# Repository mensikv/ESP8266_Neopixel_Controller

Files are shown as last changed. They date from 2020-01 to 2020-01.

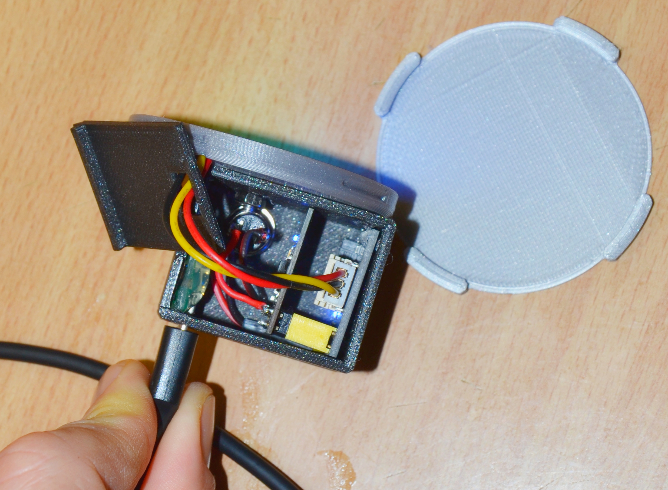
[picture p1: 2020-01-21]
img/WS2812B_controller_5.JPG

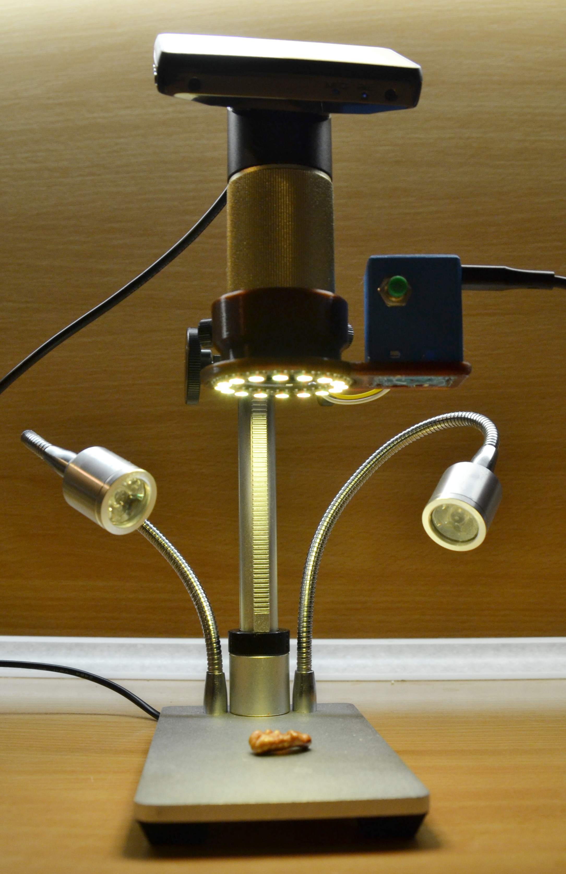
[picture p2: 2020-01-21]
img/ADSM201_WS2812B_ring_2.JPG

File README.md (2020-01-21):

# ESP8266 Neopixel Controller
I have bought a couple of ESP-01S boards without any project really in my mind. But recently I have discovered cool looking WS2812B (Neopixel) adapters for these boards, so that gave me an idea for a project.

After several iterations I have developed little device, that enables to control WS2812B strips/rings either throught web interface, through MQTT commands or through REST API. It has also one button, that can switch various colors and effects. 
What can it do:
* provides web interface that enables to select any color, save it to EEPROM, start an effect
* when enabled, the WS1228B strips can be controlled via MQTT commands (color, effect, off)
* REST API is also available to set color or effect
* button click cycles through saved colors, double click cycles through available effects and long click turns Neopixels off

Project can be used in home automation systems as it provides several interfaces that could be easily integrated into for example Node-Red.

**WIFI network is required**.

## Prerequisites
### Hardware
It is possible to use any ESP8266 board, but I used specifically ESP-01S boards (non-affiliated links):
* [WS2812B adapter for ESP-01S](https://www.aliexpress.com/item/32894024068.html?spm=a2g0s.9042311.0.0.27424c4d4m1lEc)
* [ESP-01S](https://www.aliexpress.com/item/32809618395.html?spm=a2g0s.9042311.0.0.27424c4deEkjUk) - you need the "S" version as it has more falsh memory (1MB) 
* [Momentary push button](https://www.aliexpress.com/item/32812446715.html?spm=a2g0s.9042311.0.0.27424c4d1w7nAk)
* [Micro USB connector](https://www.aliexpress.com/item/32394000673.html?spm=a2g0s.9042311.0.0.27424c4dAlAlbz)
* [16x WS1228B (Neopixel) ring](https://www.aliexpress.com/item/33006920763.html?spm=a2g0s.9042311.0.0.27424c4dT2O7Fa) - you should be able to use even more Neopixels

The push button is connected between GND and GPIO3 on the ESP-01S. When using the WS2812B adapter for ESP-01S, the control pin is GPIO2.

### Software
Project was tested with the following versions:
* Arduino IDE 1.8.10
* ESP8266 core 2.6.0
* [ESP8266 Sketch Data Upload](https://github.com/esp8266/arduino-esp8266fs-plugin)

Libraries:
* [ArduinoJSON 6.12.0](https://github.com/bblanchon/ArduinoJson)
* [ESP_EEPROM 2.0.0](https://github.com/jwrw/ESP_EEPROM)
* [FastLed 3.3](https://github.com/FastLED/FastLED)
* [WifiManages 0.15.0-beta](https://github.com/tzapu/WiFiManager)
* [PubSubClient 2.7](https://github.com/knolleary/pubsubclient)
* [PinButton](https://github.com/poelstra/arduino-multi-button)

## Setup
1. Download content of this repository to your Arduino folder (probably `~\Documents\Arduino\ESP8266_Neopixel_Controller`, folder should contain `*.ino` file and `data` folder) and then open `ESP8266_Neopixel_Controller.ino`.
1. Set pin for WS2812B input `#define LED_DATA_PIN 2` - if you are using the adapter board, do not change
1. Set number of WS2812B LEDs `#define NUM_LEDS 16`
1. Set pin for the button `#define BUTTON_PIN 3`
1. You can set a hostname by changing `#define ESP_HOSTNAME "NPCTRL001"`
1. If you want to enable MQTT API (choosing colors with MQTT messages), uncomment `//#define USE_MQTT`
   1. In section `#ifdef USE_MQTT` set connection to your MQTT broker and topics, you want to use.
   1. You should increase `MQTT_MAX_PACKET_SIZE` in PubSubClient.h. For 10 colors is 512 sufficient - `#define MQTT_MAX_PACKET_SIZE 512`
1. If you want to assign static IP address to the board in your WIFI network, uncomment and set following line `//wifiManager.setSTAStaticIPConfig(IPAddress(192,168,0,99), IPAddress(192,168,0,1), IPAddress(255,255,255,0));`
1. Choose the right board and select Flash size with at least 128kB SPIFFS, for ESP-01S it should be "Generic ESP8266 Module" and "1M (128k SPIFFS)"
1. Upload the code.
1. Run ESP8266 Sketch Data Upload to upload content of `/data` folder to SPIFFS on ESP8266. Great article is [Chapter 11 - SPIFFS](https://tttapa.github.io/ESP8266/Chap11%20-%20SPIFFS.html). ESP8266 Sketch Data Upload plug-in to load data on SPIFFS can be downloaded from [here](https://github.com/esp8266/arduino-esp8266fs-plugin). `/data` folder contains html code, CSS styles and JavaScript code for the webserver.
   1. Before stating upload to SPIFFS make sure, that Serial monitor window is not opened, otherwise the upload will fail.
1. Now the ESP8266 will start in AP mode and creates WIFI network with the name you set as hostname. Connect to this network and you should be redirected to URL 192.168.0.1 (if not, enter this address in your browser). On this page set up WIFI connection to your network. ESP8266 will try to connect to it.
1. Either check your router or Serial monitor to find out, what IP address the ESP8266 got. Enter this address in your browser.
1. You enter a web interface with 2 tabs, the 1st tab is used to set color of Neopixels or start an effect (it is empty, until you  save some colots). The 2nd tab is used to choose and save new colors.

## REST API
The provided web interface itself uses this REST API and you can easily integrate it in other projects.
* GET commands
  * http://IPADDRESS/api?color=RRGGBB&brightness=xx
    * set color of the Neopixels, returns JSON with information about success or error, brightness from 0 to 100
  * http://IPADDRESS/api?all=1
    * returns JSON with saved colors
  * http://IPADDRESS/api?off=1
    * turn Neopixels off, returns JSON with information about success or error
  * http://IPADDRESS/api?effect=effect_name
    * display desired effect, returns JSON with information about success or error, effect names: "rainbow", "rainbowGl", "confetti", "sinelon", "bpm", "juggle", "fire2012", "cylon", "sparkle", "snowspark", "meteor", "theatre"
* POST commands
  * http://IPADDRESS/api?save=1&color=RRGGBB&brightness=xx
    * save new color to EEPROM, returns JSON with information about success or error
  * http://IPADDRESS/api?delete=1&color=RRGGBB&brightness=xx
    * delete color from EEPROM, returns JSON with information about success or error

## MQTT API
If you enable MQTT API, then the ESP8266 will wait for commands in topic:
* MQTT_TOPIC/cmd/color
  * payload: RRGGBB/xx
    * set color and brightness of Neopixels, brightness from 0 to 100
* MQTT_TOPIC/cmd/effect
  * payload: effect_name
    * starts chosen effect: "rainbow", "rainbowGl", "confetti", "sinelon", "bpm", "juggle", "fire2012", "cylon", "sparkle", "snowspark", "meteor", "theatre"
* MQTT_TOPIC/cmd/all
  * returns JSON with saved colors in topic MQTT_TOPIC/rspn
* MQTT_TOPIC/cmd/off
  * turns Neopixels off

All commands return response JSON in topic MQTT_TOPIC/rspn.

## Button interface
You can use button clicks to set color, start an effect or turn Neopixels off. The button should be connected between GND and GPIO3 on the ESP01-S board (defined as BUTTON_PIN).
* Single click - sets next saved color
* Double click - starts next effect
* Long click - turns Neopixels off

## STL for case
In the folder `stl` you will find `*.stl` files for your 3D printer, so you can print nice case for this project.
More information about the case and photos can be found on [Thingiverse](https://www.thingiverse.com/thing:4118976).

If you happen to have [Andonstar ADSM201 microscope](https://www.aliexpress.com/item/32614052280.html?spm=2114.12010612.8148356.5.1d8e66adaiGyX6), you will find there a mount for this project to bring more light to yout microscope sessions.

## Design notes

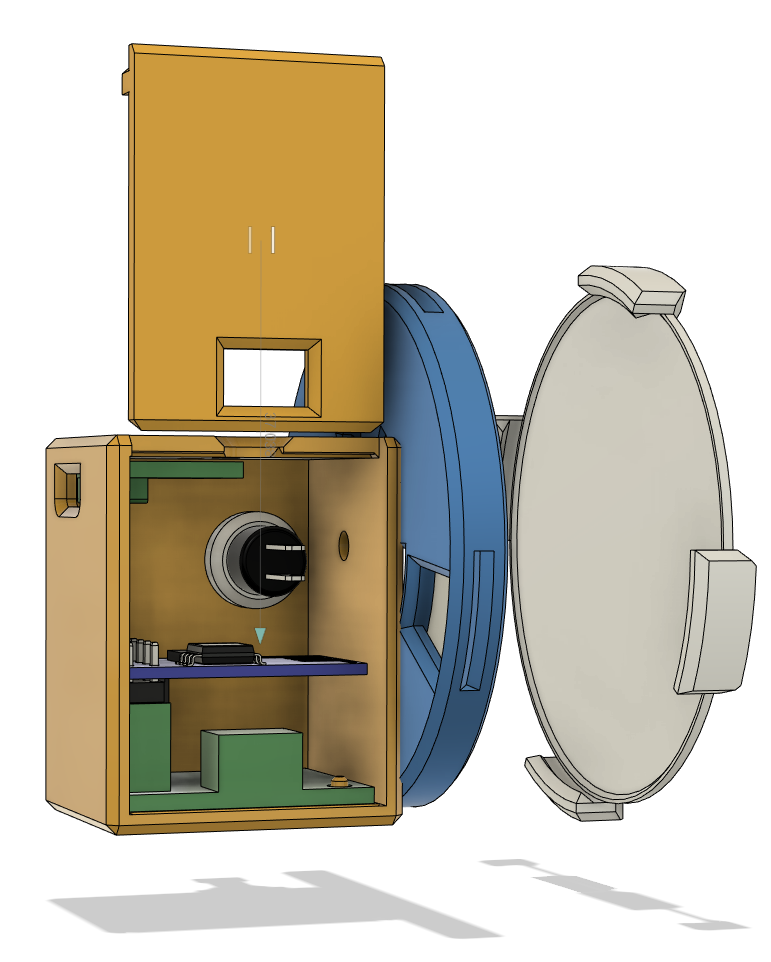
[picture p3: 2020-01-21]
img/WS2812B_controller_7.png

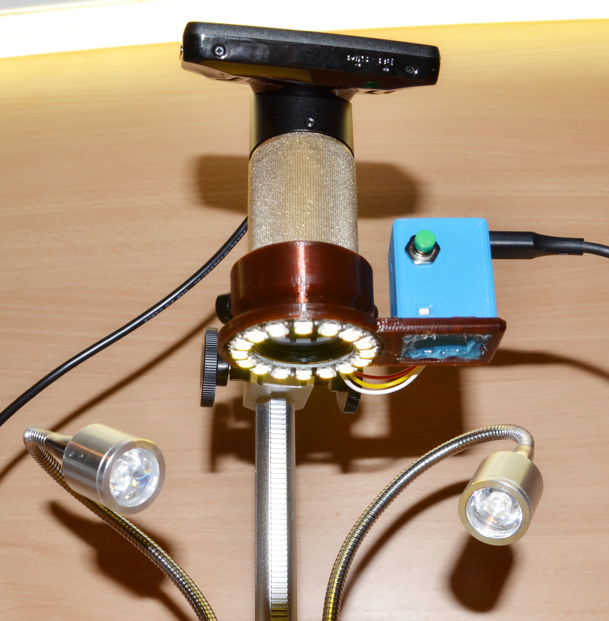
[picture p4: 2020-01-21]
img/ADSM201_WS2812B_ring_3.JPG

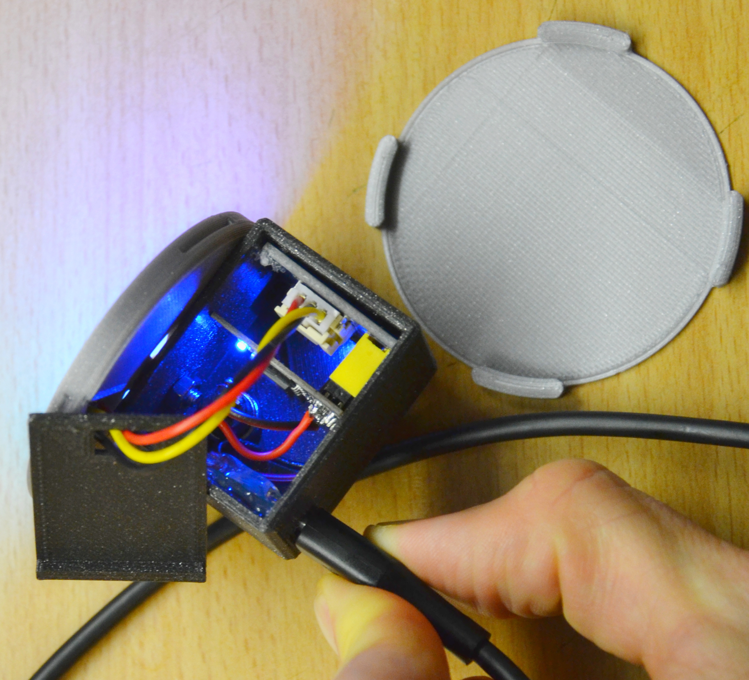
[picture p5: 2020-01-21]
img/WS2812B_controller_6.JPG

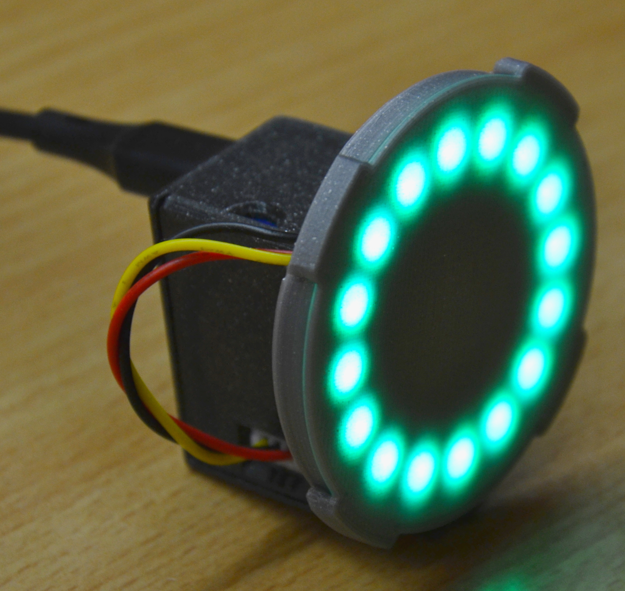
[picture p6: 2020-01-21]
img/WS2812B_controller_2.JPG

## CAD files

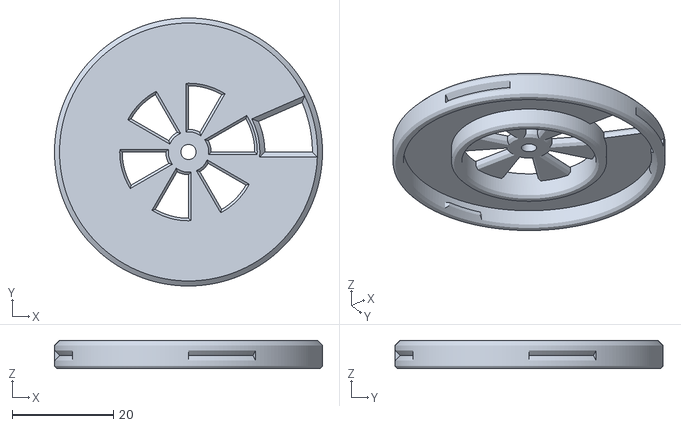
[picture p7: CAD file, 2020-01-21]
stl/WS2812B_ring_16.stl
53.0 x 53.0 x 5.60

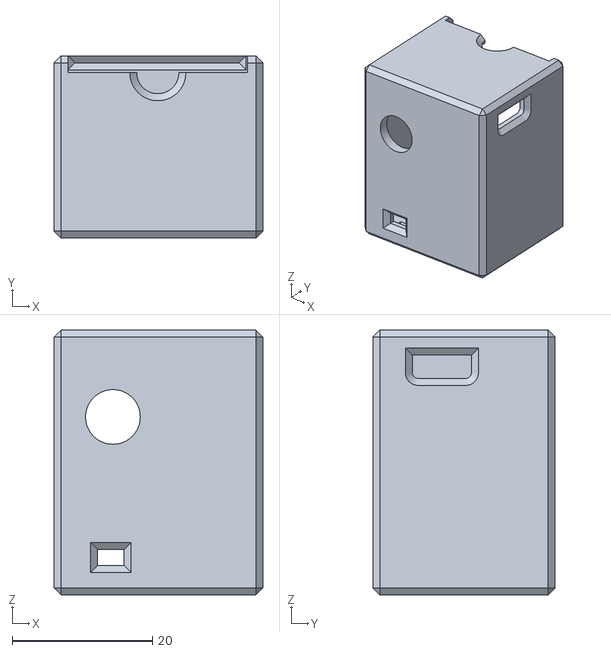
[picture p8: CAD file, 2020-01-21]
stl/WS2812B_controller_box.stl
29.8 x 26.0 x 37.8

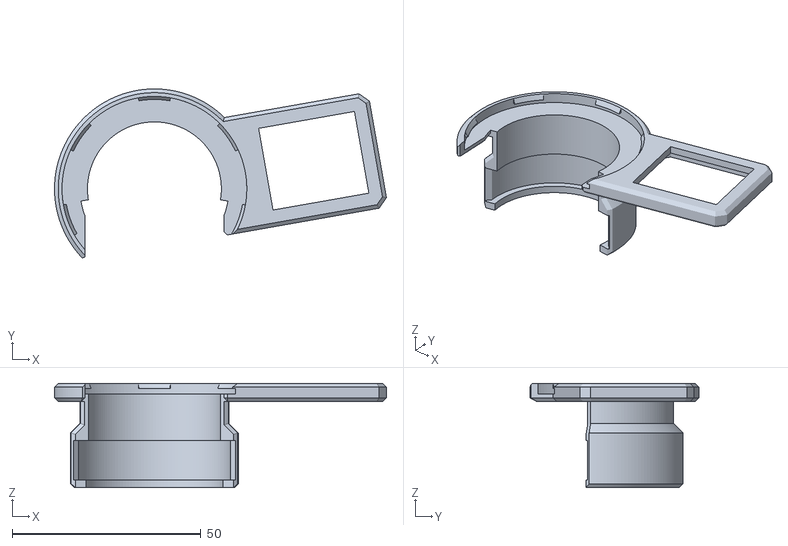
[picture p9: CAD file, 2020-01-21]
stl/ADSM201_WS2812B_ring_holder.stl
88.0 x 44.9 x 27.6

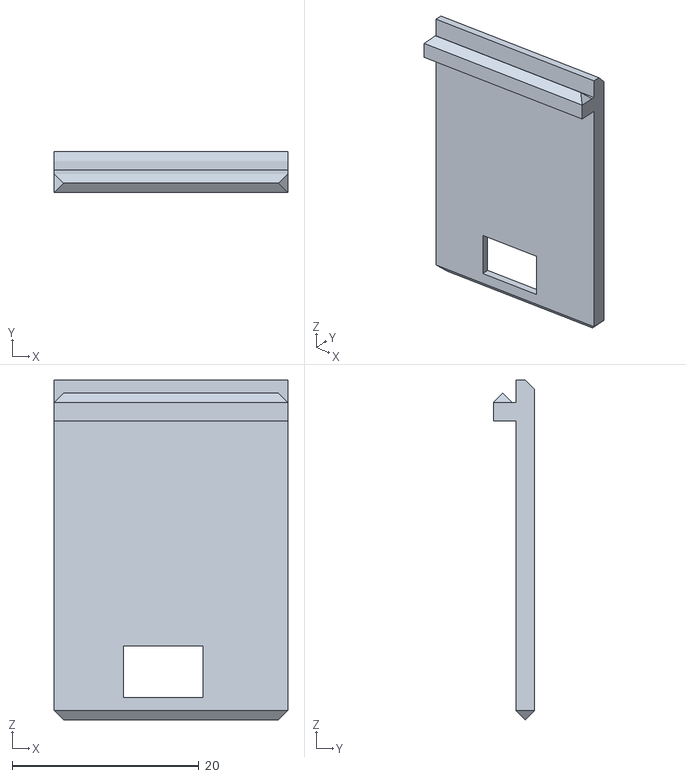
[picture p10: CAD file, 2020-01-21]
stl/WS2812B_controller_box_cover.stl
25.0 x 4.40 x 36.4

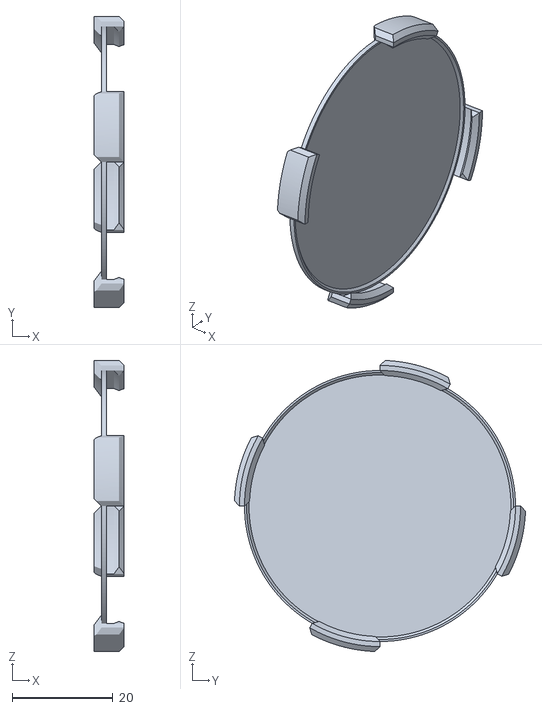
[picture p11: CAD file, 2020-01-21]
stl/WS2812B_ring_16_diffuser.stl
6.00 x 57.8 x 57.8

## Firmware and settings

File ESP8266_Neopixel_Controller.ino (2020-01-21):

/*
  ####
  ## ESP8266 Neopixel Controller
  ####
  I have designed it for ESP-01S module, but you can use any ESP8266 board.
  ESP-01S Arduino IDE setting:
    Board: Generic ESP8266 Module
    Flash size: 1M (128k SPIFFS)
    Flash Mode: QIO
    Reset method: no dtr, no_sync
  When you want to erase EEPROM: Erase Flash: All Flash Contents

  upload code and then upload files

  use ESP8266 Sketch Data Upload to upload files to ESP8266 SPIFFS: // https://github.com/esp8266/arduino-esp8266fs-plugin
    data\bootstrap.min.css.gz
    data\bootstrap.min.js.gz
    data\favicon.ico
    data\index.html.gz
    data\iro.min.js.gz
    data\jquery-3.4.1.min.js.gz

  Tested with versions:
    Arduino IDE 1.8.10
    ESP8266 core 2.6.0

  Libraries:
    ArduinoJSON 6.12.0
    ESP_EEPROM 2.0.0
    FastLed 3.3
    WifiManages 0.15.0-beta
    PubSubClient 2.7
    you should increase MQTT_MAX_PACKET_SIZE in PubSubClient.h for 10 colors is 512 sufficient
      #define MQTT_MAX_PACKET_SIZE 512

  REST API:
   GET:
    /api?color=RRGGBB&brightness=xx   - set color of the Neopixels, returns JSON with information about success or error
    /api?all=1                        - returns JSON with saved colors
    /api?off=1                        - turn Neopixels off, returns JSON with information about success or error
    /api?effect=effect_name           - display desired effect, returns JSON with information about success or error, effect names in variable char Effects[][10]
   POST:
    /api?save=1&color=RRGGBB&brightness=xx   - save new color to EEPROM, returns JSON with information about success or error
    /api?delete=1&color=RRGGBB&brightness=xx - delete color from EEPROM, returns JSON with information about success or error

  MQTT API:
   Commands:
    /cmd/color ; payload: RRGGBB/xx
    /cmd/all
    /cmd/off
    /cmd/effect ; payload: effect_name
   Returns JSON in:
    /rspn      ; payload: JSON

  BUTTON actions:
    click: next saved color
    double click: next effect
    long click: neopixels off
*/

#include <Arduino.h>
#include <FS.h>
#include <ESP8266WiFi.h>          //ESP8266 Core WiFi Library
#include <DNSServer.h>            //Local DNS Server used for redirecting all requests to the configuration portal - needed for WifiManager
#include <ESP8266WebServer.h>     //Local WebServer used to serve the configuration portal

#include <WiFiManager.h>          // https://github.com/tzapu/WiFiManager WiFi Configuration Magic
#include <ESP_EEPROM.h>           // https://github.com/jwrw/ESP_EEPROM
#include <PinButton.h>            // https://github.com/poelstra/arduino-multi-button
#include <ArduinoJson.h>          // https://github.com/bblanchon/ArduinoJson

#include <FastLED.h>              // https://github.com/FastLED/FastLED

/*
  ## WIFI Manager function
  When your ESP starts up, it sets it up in Station mode and tries to connect to a previously saved Access Point
  if this is unsuccessful (or no previous network saved) it moves the ESP into Access Point mode and spins up a DNS and WebServer (ip 192.168.0.1)
  using any wifi enabled device with a browser (computer, phone, tablet) connect to the newly created Access Point
  because of the Captive Portal and the DNS server you will either get a 'Join to network' type of popup or get any domain you try to access redirected to the configuration portal
  choose one of the access points scanned, enter password, click save
  ESP will try to connect. If successful, it relinquishes control back to your app. If not, reconnect to AP and reconfigure.
*/


// ==================== Settings ====================
#define ESP_HOSTNAME    "NPCTRL001"
#define KBAUDRATE       115200         // The Serial connection baud rate.
#define COLOR_COUNT     10             // maximum number of saved colors

#define NUM_LEDS                   16
//#define LED_DATA_PIN               D2  // for Wemos D1 Mini
#define LED_DATA_PIN               2  // for ESP-01S with WS2812B adapter
#define LED_TYPE                   WS2812B
#define COLOR_ORDER                GRB
#define EFFECT_BRIGHTNESS          96
#define EFFECT_FRAMES_PER_SECOND   30

//#define BUTTON_PIN                 D3  // Pin where the button is connected on Wemos D1 Mini
#define BUTTON_PIN                 3  // for ESP-01S - RX pin on ESP-01S - Pin where the button is connected

// MQTT API - comment out, if you do not need it
#define USE_MQTT

#ifdef USE_MQTT
  #include <PubSubClient.h>                     // https://github.com/knolleary/pubsubclient
  #define MQTT_SERVER             "192.168.1.100"
  #define MQTT_USERNAME           "username"
  #define MQTT_PASSWORD           "password"
  #define MQTT_TOPIC              ESP_HOSTNAME
  #define MQTT_CMD_TOPIC          MQTT_TOPIC "/cmd"
  #define MQTT_RSPN_TOPIC         MQTT_TOPIC "/rspn"
  #define MQTT_LAST_WILL_TOPIC    MQTT_TOPIC "/live"
  #define MQTT_LAST_WILL          "OFF"
  #define MQTT_MAX_PAYLOAD_LENGTH 15
#endif


// ==================== Constants and helper macros ====================
#define ARRAY_SIZE(A)             (sizeof(A) / sizeof((A)[0]))

#define BUTTON_NO_CLICK 0
#define BUTTON_SINGLE_CLICK 1
#define BUTTON_DOUBLE_CLICK 2
#define BUTTON_LONG_CLICK   3


// ==================== Types definition ====================
enum TProgram_States {NEOPIXEL_OFF, NEOPIXEL_COLOR, NEOPIXEL_EFFECT};

// Effects - each is defined as a separate function below.
typedef void (*effectFunctionType)();

typedef struct {
  char effectName[15];
  effectFunctionType effectFunction;
  int16_t effectFrames;
} effectType;

// structure to hold information about a color and brightness of Neopixels
typedef struct {
  uint8_t rgb[3];                           // RGB color: rbg[0] - R, rbg[1] - G, rbg[2] - B
  uint8_t brtns;                            // brightness of the color
} colorType;

// Settings
typedef struct {
  uint8_t colorCount;                  // 1 byte, Count of saved colors
  TProgram_States programState;        // Actual state of running program
  uint8_t activeColor;                 // index of saved color that is displayed
  uint8_t activeEffect;                // index of effect that is displayed
} npControllerSettingType;

typedef struct {                        // structure, that is written into the EEPROM memory
  uint32_t                crc32;        // 4 bytes
  npControllerSettingType npControllerSetting;
  colorType               colors[COLOR_COUNT+1]; // index COLOR_COUNT is for new color, not yet saved, but requested
} npControllerEEPROMType;


// ==================== Global variables ====================
void rainbow();
void rainbowWithGlitter();
void confetti();
void sinelon();
void bpm();
void juggle();
void fire2012();
void cylon();
void sparkle();
void snowsparkle();
void meteor();
void theatre();

effectType effects[] = {
  {"rainbow",   rainbow,            EFFECT_FRAMES_PER_SECOND * 5},
  {"rainbowGl", rainbowWithGlitter, EFFECT_FRAMES_PER_SECOND * 5},
  {"confetti",  confetti,           EFFECT_FRAMES_PER_SECOND * 5},
  {"sinelon",   sinelon,            EFFECT_FRAMES_PER_SECOND * 5},
  {"bpm",       bpm,                EFFECT_FRAMES_PER_SECOND * 5},
  {"juggle",    juggle,             EFFECT_FRAMES_PER_SECOND},
  {"fire2012",  fire2012,           EFFECT_FRAMES_PER_SECOND},
  {"cylon",     cylon,              EFFECT_FRAMES_PER_SECOND * 4},
  {"sparkle",   sparkle,            EFFECT_FRAMES_PER_SECOND},
  {"snowspark", snowsparkle,        EFFECT_FRAMES_PER_SECOND},
  {"meteor",    meteor,             EFFECT_FRAMES_PER_SECOND * 2},
  {"theatre",   theatre,            EFFECT_FRAMES_PER_SECOND/2}};

int16_t actualFrame;                              // contains the number of actual Frame for chosen effect
npControllerEEPROMType    npControllerEEPROM;     // contains all saved colors, CRC32 and other informations
colorType                 *colors;                // saved colors the application operates with
npControllerSettingType   *npControllerSetting;   // Will containt info about active color/effect, number of saved colors...
uint32_t lastNeopixelRefresh;                     // actual time in program in ms
uint8_t  changeNeopixel;                          // 1 if effect or color should be changed

// memory structure to store the state of individual LEDs
CRGB leds[NUM_LEDS];

// Strings for storing JSON
String strOutput;

// Web serever will run on port 80
ESP8266WebServer server(80);

// Create a new button object, listening on pin BUTTON_PIN
PinButton myButton(BUTTON_PIN);

#ifdef USE_MQTT
  WiFiClient espWifiClient;
  PubSubClient mqtt_client(espWifiClient);
#endif


// ==================== JSON responses ====================
void allResponse () {
  // JSON:{"rsT":"all", "rsE":"", "rsV":[{"rgb":"aabbcc","brtns":50},{"rgb":"994422","brtns":100}]}
  const uint16_t capacityResponseJSON = JSON_ARRAY_SIZE(COLOR_COUNT) + COLOR_COUNT*JSON_OBJECT_SIZE(2) + JSON_OBJECT_SIZE(3) + COLOR_COUNT * 30;
  StaticJsonDocument<capacityResponseJSON> responseJSON;
  responseJSON["rsT"] = "all";
  responseJSON["rsE"] = "";
  strOutput = "";
  JsonArray rsV = responseJSON.createNestedArray("rsV");
  for (uint8_t i = 0; i < npControllerSetting->colorCount; i++) {
    JsonObject colorElem = rsV.createNestedObject();
    char rgbStr[7];
    sprintf(rgbStr, "%02X%02X%02X", colors[i].rgb[0], colors[i].rgb[1], colors[i].rgb[2]);
    colorElem["rgb"] = rgbStr;
    colorElem["brtns"] = colors[i].brtns;
  }
  serializeJson(responseJSON, strOutput);
}

void colorResponse (uint8_t colorResult) {
  // JSON: {"rsT":"color", "rsE":"", "rsV":{"rgb":"aabbcc","brtns":50}}
  const uint16_t capacityResponseJSON = JSON_OBJECT_SIZE(2) + JSON_OBJECT_SIZE(3) + 40;
  StaticJsonDocument<capacityResponseJSON> responseJSON;
  responseJSON["rsT"] = "color";
  responseJSON["rsE"] = "";
  strOutput = "";
  if (colorResult != 1) {
    responseJSON["rsE"] = "Wrong format of color/brightness.";
  } else {
    JsonObject rsV = responseJSON.createNestedObject("rsV");
    char rgbStr[7];
    uint8_t colorIndex = npControllerSetting->activeColor;
    sprintf(rgbStr, "%02X%02X%02X", colors[colorIndex].rgb[0], colors[colorIndex].rgb[1], colors[colorIndex].rgb[2]);
    rsV["rgb"] = rgbStr;
    rsV["brtns"] = colors[colorIndex].brtns;
  }
  serializeJson(responseJSON, strOutput);
}

void offResponse () {
  // JSON: {"rsT":"off", "rsE":"", "rsV":1}
  const int capacityResponseJSON = JSON_OBJECT_SIZE(3) + 20;
  StaticJsonDocument<capacityResponseJSON> responseJSON;
  responseJSON["rsT"] = "off";
  responseJSON["rsE"] = "";
  strOutput = "";
  responseJSON["rsV"] = 1;
  serializeJson(responseJSON, strOutput);
}

void effectResponse (uint8_t effectResult) {
  // JSON: {"rsT":"effect", "rsE":"", "rsV":"EFFECT_NAME"}
  const int capacityResponseJSON = JSON_OBJECT_SIZE(3) + 40;
  StaticJsonDocument<capacityResponseJSON> responseJSON;
  responseJSON["rsT"] = "effect";
  responseJSON["rsE"] = "";
  strOutput = "";
  if (effectResult != 1) {
    responseJSON["rsE"] = "Wrong name of effect.";
  } else {
    responseJSON["rsV"] = effects[npControllerSetting->activeEffect].effectName;
  }
  serializeJson(responseJSON, strOutput);
}

void saveResponse (uint8_t saveResult) {
  // JSON: {"rsT":"save", "rsE":"", "rsV":{"rgb":"aabbcc","brtns":50}}
  const int capacityResponseJSON = JSON_OBJECT_SIZE(2) + JSON_OBJECT_SIZE(3) + 40;
  StaticJsonDocument<capacityResponseJSON> responseJSON;
  responseJSON["rsT"] = "save";
  responseJSON["rsE"] = "";
  strOutput = "";
  if (saveResult != 1) {
    if (saveResult == 0) responseJSON["rsE"] = "Could not save the new color to EEPROM.";
    else if (saveResult == 2) responseJSON["rsE"] = "Wrong format for color/brightness.";
    else if (saveResult == 3) responseJSON["rsE"] = "Color is already saved.";
    else responseJSON["rsE"] = "Maximum number of colors saved.";
  } else {
    JsonObject rsV = responseJSON.createNestedObject("rsV");
    char rgbStr[7];
    uint8_t colorIndex = npControllerSetting->colorCount - 1;
    sprintf(rgbStr, "%02X%02X%02X", colors[colorIndex].rgb[0], colors[colorIndex].rgb[1], colors[colorIndex].rgb[2]);
    rsV["rgb"] = rgbStr;
    rsV["brtns"] = colors[colorIndex].brtns;
  }
  serializeJson(responseJSON, strOutput);
}

void deleteResponse (uint8_t deleteResult, char rgbHex[], uint8_t brightness) {
  // JSON: {"rsT":"delete", "rsE":"","rsV":{"rgb":"aabbcc","brtns":50}}
  const int capacityResponseJSON = JSON_OBJECT_SIZE(2) + JSON_OBJECT_SIZE(3) + 50;
  StaticJsonDocument<capacityResponseJSON> responseJSON;
  responseJSON["rsT"] = "delete";
  responseJSON["rsE"] = "";
  strOutput = "";
  if (deleteResult != 1) {
    if (deleteResult == 0) responseJSON["rsE"] = "Error during saving to EEPROM.";
    else if (deleteResult == 2) responseJSON["rsE"] = "Wrong format for color/brightness.";
    else responseJSON["rsE"] = "Color not found.";
  } else {
    JsonObject rsV = responseJSON.createNestedObject("rsV");
    rsV["rgb"] = rgbHex;
    rsV["brtns"] = brightness;
  }
  serializeJson(responseJSON, strOutput);
}
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
void loop() {
  // Handle HTTP communication
  server.handleClient();

#ifdef USE_MQTT
  if (!mqtt_client.connected()) {
    mqttConnect();
  }
  mqtt_client.loop();
#endif

  // Read hardware pin, convert to click events
  myButton.update();
  if      (myButton.isSingleClick()) processClick(BUTTON_SINGLE_CLICK);
  else if (myButton.isDoubleClick()) processClick(BUTTON_DOUBLE_CLICK);
  else if (myButton.isLongClick())   processClick(BUTTON_LONG_CLICK);

  // Handle Neopixels
  effectType *activeEffect;
  switch (npControllerSetting->programState) {
    case NEOPIXEL_COLOR:
      if (changeNeopixel) {
        uint8_t activeColor = npControllerSetting->activeColor;
        Serial.printf("New color: #%02X%02X%02X/%i\n", colors[activeColor].rgb[0], colors[activeColor].rgb[1], colors[activeColor].rgb[2], colors[activeColor].brtns);
        CRGB color = CRGB( colors[activeColor].rgb[0], colors[activeColor].rgb[1], colors[activeColor].rgb[2]);
        uint8_t brightness = map(colors[activeColor].brtns, 0, 100, 0, 255);
        FastLED.showColor(color, brightness);
      }
      break;

    case NEOPIXEL_EFFECT:
      activeEffect = &effects[npControllerSetting->activeEffect];
      if (changeNeopixel) {
        Serial.printf("New effect: %s\n", activeEffect->effectName);
        FastLED.setBrightness(EFFECT_BRIGHTNESS);
        lastNeopixelRefresh = 0;
        actualFrame = 0;
      }

      if ((lastNeopixelRefresh + (1000/EFFECT_FRAMES_PER_SECOND)) <= millis()) {  // it is time for new frame
        // Call the current pattern function once, updating the 'leds' array

        (activeEffect->effectFunction)();

        actualFrame++;
        if (actualFrame >= activeEffect->effectFrames) {
          actualFrame = 0;
        }

        // send the 'leds' array out to the actual LED strip
        FastLED.show();

        lastNeopixelRefresh = millis();
      }
      break;

    case NEOPIXEL_OFF:
      if (changeNeopixel) {
        Serial.println(F("Neopixels off"));
        FastLED.clear(true);
      }
      break;
  }

  if (changeNeopixel) {
    changeNeopixel = 0;
  }
}



void rainbow() {
  uint8_t effectIndex = npControllerSetting->activeEffect;
  uint8_t hue = map(actualFrame, 0, effects[effectIndex].effectFrames -1, 0, 255);
  // FastLED's built-in rainbow generator
  fill_rainbow( leds, NUM_LEDS, hue, 7);
}

void rainbowWithGlitter() {
  // built-in FastLED rainbow, plus some random sparkly glitter
  rainbow();
  addGlitter(40);
}

void addGlitter( fract8 chanceOfGlitter)
{
  if( random8() < chanceOfGlitter) {
    leds[ random16(NUM_LEDS) ] += CRGB::White;
  }
}

void confetti() {
  uint8_t effectIndex = npControllerSetting->activeEffect;
  uint8_t hue = map(actualFrame, 0, effects[effectIndex].effectFrames -1, 0, 255);

  // random colored speckles that blink in and fade smoothly
  fadeToBlackBy( leds, NUM_LEDS, 10);
  int pos = random16(NUM_LEDS);
  leds[pos] += CHSV( hue + random8(64), 200, 255);
}

void sinelon() {
  uint8_t effectIndex = npControllerSetting->activeEffect;
  uint8_t hue = map(actualFrame, 0, effects[effectIndex].effectFrames -1, 0, 255);

  // a colored dot sweeping back and forth, with fading trails
  fadeToBlackBy( leds, NUM_LEDS, 20);
  // Beat generators which return sine waves in a specified number of Beats Per Minute.
  // Sine wave beat generators can specify a low and  high range for the output.
  //   beatsin16( BPM, low16, high16) = (sine(beatphase) * (high16-low16)) + low16
  //   beatsin16( BPM, uint16_t low, uint16_t high) returns a 16-bit value
  //                    that rises and falls in a sine wave, 'BPM' times per
  //                    minute, between the values of 'low' and 'high'.
  int pos = beatsin16( 13, 0, NUM_LEDS-1 );
  leds[pos] += CHSV( hue, 255, 192);
}

void bpm() {
  uint8_t effectIndex = npControllerSetting->activeEffect;
  uint8_t hue = map(actualFrame, 0, effects[effectIndex].effectFrames -1, 0, 255);

  // colored stripes pulsing at a defined Beats-Per-Minute (BPM)
  uint8_t BeatsPerMinute = 62;
  CRGBPalette16 palette = PartyColors_p;
  uint8_t beat = beatsin8( BeatsPerMinute, 64, 255);
  for( int i = 0; i < NUM_LEDS; i++) { //9948
    leds[i] = ColorFromPalette(palette, hue+(i*2), beat-hue+(i*10));
  }
}

void juggle() {
  // eight colored dots, weaving in and out of sync with each other
  fadeToBlackBy( leds, NUM_LEDS, 20);
  byte dothue = 0;
  for( int i = 0; i < 8; i++) {
    leds[beatsin16( i+7, 0, NUM_LEDS-1 )] |= CHSV(dothue, 200, 255);
    dothue += 32;
  }
}

// Fire2012 by Mark Kriegsman, July 2012
// as part of "Five Elements" shown here: http://youtu.be/knWiGsmgycY
////
// This basic one-dimensional 'fire' simulation works roughly as follows:
// There's a underlying array of 'heat' cells, that model the temperature
// at each point along the line.  Every cycle through the simulation,
// four steps are performed:
//  1) All cells cool down a little bit, losing heat to the air
//  2) The heat from each cell drifts 'up' and diffuses a little
//  3) Sometimes randomly new 'sparks' of heat are added at the bottom
//  4) The heat from each cell is rendered as a color into the leds array
//     The heat-to-color mapping uses a black-body radiation approximation.
//
// Temperature is in arbitrary units from 0 (cold black) to 255 (white hot).
//
// This simulation scales it self a bit depending on NUM_LEDS; it should look
// "OK" on anywhere from 20 to 100 LEDs without too much tweaking.
//
// I recommend running this simulation at anywhere from 30-100 frames per second,
// meaning an interframe delay of about 10-35 milliseconds.
//
// Looks best on a high-density LED setup (60+ pixels/meter).
//
//
// There are two main parameters you can play with to control the look and
// feel of your fire: COOLING (used in step 1 above), and SPARKING (used
// in step 3 above).
//
// COOLING: How much does the air cool as it rises?
// Less cooling = taller flames.  More cooling = shorter flames.
// Default 50, suggested range 20-100
#define COOLING  55

// SPARKING: What chance (out of 255) is there that a new spark will be lit?
// Higher chance = more roaring fire.  Lower chance = more flickery fire.
// Default 120, suggested range 50-200.
#define SPARKING 120


void fire2012() {
// Array of temperature readings at each simulation cell
  static byte heat[NUM_LEDS];

  // Step 1.  Cool down every cell a little
    for( int i = 0; i < NUM_LEDS; i++) {
      heat[i] = qsub8( heat[i],  random8(0, ((COOLING * 10) / NUM_LEDS) + 2));
    }

    // Step 2.  Heat from each cell drifts 'up' and diffuses a little
    for( int k= NUM_LEDS - 1; k >= 2; k--) {
      heat[k] = (heat[k - 1] + heat[k - 2] + heat[k - 2] ) / 3;
    }

    // Step 3.  Randomly ignite new 'sparks' of heat near the bottom
    if( random8() < SPARKING ) {
      int y = random8(7);
      heat[y] = qadd8( heat[y], random8(160,255) );
    }

    // Step 4.  Map from heat cells to LED colors
    for( int j = 0; j < NUM_LEDS; j++) {
      CRGB color = HeatColor( heat[j]);
      int pixelnumber;
      pixelnumber = j;
      leds[pixelnumber] = color;
    }
}

void cylon(){
  CRGB color = CRGB(0xff0000);
  uint8_t EyeSize = 2;
  uint8_t direction = true;
  uint8_t step_;

  uint8_t effectIndex = npControllerSetting->activeEffect;

  if (actualFrame >= (effects[effectIndex].effectFrames/2)) {
    direction = false;
    step_ = map(actualFrame, effects[effectIndex].effectFrames/2, effects[effectIndex].effectFrames -1, 0, NUM_LEDS - EyeSize);
  } else {
    step_ = map(actualFrame, 0, (effects[effectIndex].effectFrames/2)-1, 0, NUM_LEDS - EyeSize);
  }

  if (direction && (step_ < NUM_LEDS - EyeSize)) leds[step_ + 2] = color/(uint8_t)5;
  else if (step_ > 2) leds[NUM_LEDS - 1 - step_ - 2] = color/(uint8_t)5;

  fadeToBlackBy( leds,NUM_LEDS, 96);

  if (direction) for (uint8_t i = 0; i < EyeSize; i++) leds[step_ + i] = color;
  else for (uint8_t i = 0; i < EyeSize; i++) leds[NUM_LEDS - 1 - step_ - i] = color;
}

void sparkle() {
  CRGB color = CRGB(0x101010);
  fadeToBlackBy( leds,NUM_LEDS, 64);
  if (random8() < 60) leds[random8(NUM_LEDS)] = color;
}

void snowsparkle() {
  CRGB colorSnow = CRGB(0x101010);
  CRGB colorWhite = CRGB(0xffffff);
  for(int i = 0; i < NUM_LEDS; i++ ) {
    leds[i] = blend( colorSnow, leds[i], 200 );
  }
  if (random8() < 60) leds[random8(NUM_LEDS)] = colorWhite;
}
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
